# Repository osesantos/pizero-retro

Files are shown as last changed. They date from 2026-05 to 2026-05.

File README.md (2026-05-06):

## Table of Contents

- [Differences from Anemoia-ESP32](#differences-from-anemoia-esp32)
- [Hardware Overview](#hardware-overview)
  - [Parts List](#parts-list)
  - [Wiring](#wiring)
    - [ILI9341 Display](#ili9341-display)
    - [Tactile Buttons](#tactile-buttons)
- [Software Setup](#software-setup)
  - [Step 1 - Install RetroPie](#step-1---install-retropie)
  - [Step 2 - Configure the SPI Display](#step-2---configure-the-spi-display)
  - [Step 3 - Configure GPIO Buttons](#step-3---configure-gpio-buttons)
  - [Step 4 - Add ROMs](#step-4---add-roms)
- [3D Model & Enclosure](#3d-model--enclosure)
- [Contributing](#contributing)
- [License](#license)

---

## Differences from Anemoia-ESP32

| Aspect | Anemoia-ESP32 | Anemoia-PiZero |
|---|---|---|
| Board | ESP32 (dual-core) | Raspberry Pi Zero (no W) |
| OS / Runtime | Arduino / bare metal | RetroPie (Raspberry Pi OS + RetroArch)|
| Display | ST7789 or ILI9341 SPI TFT | ILI9341 SPI TFT (240×320) |
| Audio | PAM8403 amplifier + speaker | None (not implemented yet) |
| ROM storage | Separate SPI microSD module | ROMs on the main OS SD card |
| Input | Various controllers | 8 tactile push buttons (GPIO) |
| Power | Battery + TP4056 charger | USB power only (no battery) |
| PCB | Custom PCB options | Hand-wired (wires / proto board) |

---

## Hardware Overview

### Parts List

| Part | Specification | Notes |
|---|---|---|
| Raspberry Pi Zero | Any revision | Pi Zero 2 W gives better emulation performance |
| SPI TFT display | ILI9341, 240×320, 2.8" | Bare module, not a touchscreen variant |
| Tactile push buttons | 12×12mm body | **6mm or 6.5mm stem height** — see note below |
| Proto board | 5×7 cm (50×70mm) | Elegoo or equivalent, 2.54mm pitch |
| MicroSD card | 8GB minimum, Class 10 | For OS + ROMs |
| USB power supply | 5V / 1A via Micro-USB | Standard phone charger works |
| Hookup wire | 28 AWG stranded | ~30cm total; solid core also works inside case |
| M2.5 × 6mm screws | Self-tapping | ×2, to mount proto board to case standoffs |
| Solder, flux | — | Standard 60/40 or lead-free |

> [!WARNING]
> **Button stem height is critical.** The top shell inner cavity is approximately 7mm deep.
> Standard 12×12×7.3mm tactile buttons (the most common size) will be 0.3mm too tall and will
> prevent the case from closing cleanly. Use **12×12×6mm** or **12×12×6.5mm** buttons, or
> carefully sand the stem tips down ~0.5mm before assembly. Test-fit the buttons in the case
> before soldering them to the proto board.

> [!NOTE]
> No audio amplifier or speaker is needed for this build. Audio support may be added in a future revision.

---

### Physical Assembly

#### Overview

The Pi Zero is soldered **directly to the proto board** (no 40-pin header) using short wire
bridges. This keeps the total stack height to ~7.5mm, which fits inside the 13mm bottom cavity
with clearance.

```
Bottom shell cavity (13mm deep)
  └── Proto board (1.6mm)
      └── Wire bridges (2mm)
          └── Pi Zero PCB (1.4mm)
              └── USB Micro-B connectors (2.5mm, bottom edge only)
                                                Total stack: ~7.5mm
```

#### Step 1 — Prepare the proto board

1. Cut the 5×7cm proto board to **65×50mm** if you want a tighter fit, or leave full-size
   (70×50mm) — both fit inside the case footprint (available X = 85→150mm = 65mm, Y = full width).
2. Mark the positions of the two Pi Zero mounting holes on the proto board. The Pi Zero's
   mounting holes are 3.5mm diameter, spaced **58mm × 23mm** centre-to-centre
   (at 3.5mm from each corner of the 65×30mm PCB edge).

#### Step 2 — Mount the Pi Zero to the proto board

1. Lay the Pi Zero face-up on the proto board, aligning the mounting holes.
2. Solder short (~10mm) wire bridges from each of the Pi Zero's 40 GPIO pads to the nearest
   proto board through-holes. You only need to bridge the pins you are actually using
   (see wiring table below) — you do not need to bridge all 40 pins.
3. **Minimum required bridges:**
   - Pin 1 (3.3V) — for display VCC
   - Pin 2 or 4 (5V) — not used in this build, skip
   - All GND pins used (Pin 6, Pin 20, Pin 14 — connect together on proto board)
   - All signal pins from the wiring tables (SPI + GPIO buttons)
4. Use a thin bead of **epoxy or hot glue** along the Pi Zero short edges to mechanically
   bond it to the proto board once you are satisfied with the wiring.

#### Step 3 — Wire the display

Run 28 AWG wires from the ILI9341 module directly to the proto board pads corresponding to
each GPIO pin. Keep wires short — route them flat against the proto board before entering the
case. The display module sits inside the top shell, held in place by the screen window bezel.

> [!TIP]
> Solder the display wires **last**, after the Pi Zero is bonded and all button wires are run.
> The display wires cross the case interior and need to be the correct length to reach the module
> without pulling tight or bunching up.

#### Step 4 — Wire the buttons

Each button has four legs in a 12×12mm square pattern; legs on opposite sides are internally
connected. Solder one leg to a GND rail on the proto board and the diagonal leg to the
corresponding GPIO wire. Buttons sit in the top shell button holes — route wires down through
the parting line gap and to the proto board.

> [!TIP]
> Use a 10cm length of wire per button before trimming. After a test fit inside the case,
> trim to the correct length and re-solder.

#### Step 5 — Seat in the case

1. Place the assembled proto board (Pi Zero face-up) into the **bottom shell**, positioning it
   so the Pi Zero USB PWR and OTG port openings align with the two Micro-USB cutouts on the
   bottom edge of the case.
   - Pi Zero left edge should align with approximately **X = 85mm** from the left end of the case.
2. Secure with **2× M2.5 × 6mm self-tapping screws** through the case floor standoffs into the
   Pi Zero mounting holes. Alternatively, use **3M VHB double-sided tape** under the proto board.
3. Route the ILI9341 module wires up to the top shell, then press-fit the display module into
   the screen window bezel.
4. Snap the top and bottom shells together. The shells are held by friction clips; no screws needed.

---

### Wiring

Anemoia-PiZero Wiring Diagram

All connections are hand-wired. The Pi Zero uses 3.3V logic on all GPIO pins, which is directly compatible with the ILI9341 display.

#### ILI9341 Display

The display is connected to the Pi Zero's hardware SPI0 bus.

| ILI9341 Signal | Pi Zero Pin | GPIO  |
|---|---|---|
| VCC | Pin 17 | 3.3V  |
| GND | Pin 20 | GND |
| CS | Pin 24 | GPIO8 (CE0) |
| RESET | Pin 22 | GPIO25 |
| DC / RS | Pin 18 | GPIO24 |
| MOSI / SDI | Pin 19 | GPIO10 (MOSI) |
| SCK / CLK | Pin 23 | GPIO11 (SCLK) |
| LED / BL | Pin 17 | 3.3V (always on) |
| MISO | - | Not connected |

> [!NOTE]
> The backlight (LED/BL) pin can be connected directly to 3.3V for always-on operation, or to a GPIO pin if you want software brightness control later.

---

#### Tactile Buttons

Each button connects between a GPIO pin and GND. The Pi's internal pull-up resistors are enabled in software.

| NES Button | Pi Zero Pin | GPIO |
|---|---|---|
| A | Pin 29 | GPIO5  |
| B | Pin 31 | GPIO6  |
| Up | Pin 33 | GPIO13 |
| Down | Pin 35 | GPIO19 |
| Left | Pin 36 | GPIO16 |
| Right | Pin 38 | GPIO20 |
| Start | Pin 40 | GPIO21 |
| Select | Pin 37 | GPIO26 |

> [!NOTE]
> These GPIO assignments are suggestions. You can remap them during the RetroArch controller configuration step. Avoid GPIO2, GPIO3 (I2C), and GPIO14/15 (UART) to prevent conflicts.

---

## Software Setup

### Step 1 - Install RetroPie

1. Download the latest **RetroPie** image for **Raspberry Pi Zero / Zero W** from the [official RetroPie website](https://retropie.org.uk/download/).
2. Flash the image to your microSD card using [Raspberry Pi Imager](https://www.raspberrypi.com/software/) or [balenaEtcher](https://etcher.balena.io/).
3. Insert the SD card into your Pi Zero and boot it up connected to an HDMI monitor first to complete initial setup.

---

### Step 2 - Configure the SPI Display

The ILI9341 display is driven by [`fbcp-ili9341`](https://github.com/juj/fbcp-ili9341) — a userspace SPI display driver that reads `/dev/fb0` (the HDMI virtual framebuffer) and pushes it directly to the ILI9341 over `/dev/spidev0.0`. This requires no kernel module or device tree overlay, and works on all Pi kernel versions.

> [!NOTE]
> The `dtoverlay=fbtft,...` and `fbtft_device` module approaches both fail on the kernel version (`5.10.x`) shipped with current RetroPie for Pi Zero. Use `fbcp-ili9341` instead.

#### 2a — Enable SPI and set the HDMI virtual resolution

Mount the SD card on your PC, or SSH/edit directly on the Pi, and open `/boot/config.txt`. Append the contents of `config/boot_config.txt` from this repo (or copy the lines below):

```
# Enable SPI bus (required for the ILI9341 display)
dtparam=spi=on

# Force HDMI output at 320x240.
# fbcp-ili9341 reads /dev/fb0 and pushes it directly to the ILI9341 over SPI.
# These settings are required even if no HDMI monitor is connected.
hdmi_force_hotplug=1
hdmi_group=2
hdmi_mode=87
hdmi_cvt=320 240 60 1 0 0 0
```

#### 2b — Install fbcp-ili9341

SSH into the Pi and run:

```bash
sudo apt update
sudo apt install -y cmake
git clone https://github.com/juj/fbcp-ili9341.git
cd fbcp-ili9341
mkdir build && cd build
cmake -DILI9341=ON \
      -DSPI_BUS_CLOCK_DIVISOR=6 \
      -DGPIO_TFT_DATA_CONTROL=24 \
      -DGPIO_TFT_RESET_PIN=25 \
      -DDISPLAY_ROTATE_180_DEGREES=ON \
      -DBACKLIGHT_CONTROL=OFF \
      -DSTATISTICS=0 \
      ..
make -j$(nproc)
sudo install fbcp-ili9341 /usr/local/bin/fbcp-ili9341
```

Parameter notes:
- `-DILI9341=ON` — selects the ILI9341 driver
- `-DSPI_BUS_CLOCK_DIVISOR=6` — sets SPI clock to `core_freq / 6` ≈ 66 MHz (safe default; increase divisor if you see corruption)
- `-DGPIO_TFT_DATA_CONTROL=24` — DC pin = GPIO24 (Pin 18)
- `-DGPIO_TFT_RESET_PIN=25` — RESET pin = GPIO25 (Pin 22)
- `-DDISPLAY_ROTATE_180_DEGREES=ON` — landscape orientation; swap for `OFF` if the image is upside-down
- `-DBACKLIGHT_CONTROL=OFF` — backlight is wired directly to 3.3V, not a GPIO
- `-DSTATISTICS=0` — disables on-screen FPS overlay

#### 2c — Test before enabling autostart

Run it manually first to confirm the display works:

```bash
sudo fbcp-ili9341
```

The RetroPie interface should appear on the screen. Press `Ctrl+C` to stop.

#### 2d — Enable autostart at boot

Add to `/etc/rc.local` before `exit 0`:

```bash
/usr/local/bin/fbcp-ili9341 &
```

If a previous `fbcp &` line exists in `/etc/rc.local`, replace it rather than adding a second line:

```bash
sudo sed -i 's|fbcp &|/usr/local/bin/fbcp-ili9341 \&|' /etc/rc.local
```

Reboot. The RetroPie interface should appear on the SPI display on every boot.

> [!TIP]
> If colours look wrong (red/blue swapped), add `-DCOLOR_ORDER_BGR=ON` to the `cmake` command and recompile. If the image is mirrored, swap `-DDISPLAY_ROTATE_180_DEGREES` between `ON` and `OFF`.

---

### Step 3 - Configure GPIO Buttons

GPIO buttons are handled by [Adafruit's `retrogame`](https://github.com/adafruit/Adafruit-Retrogame) — a userspace daemon that reads GPIO pins and emits keyboard events via `/dev/uinput`, making the buttons visible to EmulationStation and RetroArch.

#### 3a — Install retrogame

SSH into the Pi and run:

```bash
sudo apt-get install -y git
git clone https://github.com/adafruit/Adafruit-Retrogame.git
cd Adafruit-Retrogame
make
sudo cp retrogame /usr/local/bin/retrogame
```

#### 3b — Install the GPIO config file

Copy `config/retrogame.cfg` from this repo to `/boot/retrogame.cfg` on the Pi:

```bash
sudo cp retrogame.cfg /boot/retrogame.cfg
```

The config maps each button to a key code using the GPIO numbers from the [Tactile Buttons](#tactile-buttons) table:

| Button | GPIO | Key emitted |
|---|---|---|
| A | 5 | Left Ctrl |
| B | 6 | Left Alt |
| Up | 13 | Up arrow |
| Down | 19 | Down arrow  |
| Left | 16 | Left arrow  |
| Right  | 20 | Right arrow |
| Start  | 21 | Enter |
| Select | 26 | Escape |

> [!NOTE]
> `/boot/retrogame.cfg` is watched live by the daemon — edits take effect immediately without restarting `retrogame`.

#### 3c — Enable autostart at boot

Add to `/etc/rc.local` before `exit 0`:

```bash
/usr/local/bin/retrogame &
```

Reboot and confirm it is running:

```bash
ps aux | grep retrogame
```

#### 3d — Test button events

Install `evtest` and verify events are emitted when buttons are pressed:

```bash
sudo apt-get install -y evtest
sudo evtest
# Select the retrogame device and press each button
```

#### 3e — Configure RetroArch input mapping

The default RetroArch input config (`/opt/retropie/configs/all/retroarch.cfg`) maps player 1 to WASD-style keys, which do **not** match the key codes emitted by `retrogame`. You must update it to match the key codes from the table above, otherwise only Start will work in-game.

Run the following to update the mappings and add a **Select + Start** hotkey combo to exit games:

```bash
sudo sed -i \
  -e 's/^input_player1_a = .*/input_player1_a = "ctrl"/' \
  -e 's/^input_player1_b = .*/input_player1_b = "alt"/' \
  -e 's/^input_player1_select = .*/input_player1_select = "escape"/' \
  -e 's/^input_player1_left = .*/input_player1_left = "left"/' \
  -e 's/^input_player1_right = .*/input_player1_right = "right"/' \
  -e 's/^input_player1_up = .*/input_player1_up = "up"/' \
  -e 's/^input_player1_down = .*/input_player1_down = "down"/' \
  /opt/retropie/configs/all/retroarch.cfg

echo -e "\ninput_enable_hotkey = \"escape\"\ninput_exit_emulator = \"enter\"" | sudo tee -a /opt/retropie/configs/all/retroarch.cfg
```

This results in the following effective mapping:

| Button | Key emitted by retrogame | RetroArch action |
|---|---|---|
| A | Left Ctrl | A |
| B | Left Alt | B |
| Up | Up arrow | D-pad up |
| Down | Down arrow | D-pad down |
| Left | Left arrow | D-pad left |
| Right  | Right arrow | D-pad right |
| Start  | Enter | Start |
| Select | Escape | Select |
| Select + Start | Escape + Enter | **Exit game** |

> [!NOTE]
> With `input_enable_hotkey = "escape"` set, Select becomes a modifier key for hotkey combos and no longer sends a bare ESC to the game. This is fine for all supported systems since Select is a game button, not an OS key.

#### 3f — Configure EmulationStation input mapping

On first launch (or after deleting the input config), EmulationStation will prompt you to map the controller. Press and hold any button to begin, then follow the on-screen prompts.

To reset the mapping and start over:

```bash
rm /opt/retropie/configs/all/emulationstation/es_input.cfg
```

Then restart EmulationStation — it will re-prompt for input configuration automatically.

---

### Step 4 - Add ROMs

1. Copy your legally obtained `.nes` ROM files to the following directory on the SD card:

```
/home/pi/RetroPie/roms/nes/
```

You can do this by:
- Mounting the SD card on your PC and copying files directly, or
- Using a USB drive: create a folder `retropie/roms/nes/` on the USB drive, plug it into the Pi, wait 30 seconds, then copy ROMs to the populated folder.

2. Restart EmulationStation. Your ROMs will appear in the NES game list.

---

## 3D Model & Enclosure

The original enclosure and 3D models from Anemoia-ESP32 are reused unchanged. All files are available in the `/3d-model` folder.

> [!NOTE]
> The Pi Zero has the same compact form factor as the ESP32 DevKit used in the original design. Minor modifications to the PCB mount points may be required depending on your specific Pi Zero revision. The hand-wired approach means no custom PCB is needed.

---

## Contributing

Pull requests are welcome. For major changes, please open an issue first to discuss what you would like to change.

---

## License

This project is licensed under the GNU General Public License v3.0 (GPLv3) - see the [LICENSE](LICENSE) file for more details.

Original Anemoia-ESP32 project by [Shim06](https://github.com/Shim06/Anemoia-ESP32).

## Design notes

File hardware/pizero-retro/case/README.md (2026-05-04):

# Anemoia-PiZero Case Files

OpenSCAD modifications to the original Anemoia-ESP32 module-based enclosure,
adapted for the Raspberry Pi Zero build.

---

## Files

| File | Description |
|---|---|
| `Anemoia-PiZero-Bottom.scad` | Modified bottom shell — removes ESP32-era port holes, adds Pi Zero USB port slots and standoff pilot holes |
| `Anemoia-PiZero-Top.scad` | Top shell — imported unchanged; screen window and button holes are already correct. Contains optional screen window widening parameters if needed. |

Both files import the original STLs from `3d-model/Anemoia-ESP32/` by relative
path. **Open the `.scad` files from the repo root, or adjust the `original_stl`
path at the top of each file if you open them from a different working directory.**

---

## What changed from the original

### Bottom shell

| Change | Original | Pi Zero |
|---|---|---|
| Left wall cutout | Micro-USB charging port (TP4056) | **Filled/removed** |
| Right wall cutout | SS12F17 power switch slot | **Filled/removed** |
| Bottom edge | No cutouts | **2× Micro-USB slots added** (PWR + OTG) |
| Floor standoffs | ESP32-DevKit mounting pattern | **2× M2.5 pilot holes added** for Pi Zero |

### Top shell

No structural changes. The existing 70mm screen window fits a standard
ILI9341 2.8" module in landscape orientation. Button holes are unchanged.

---

## Pi Zero placement inside the case

```
Case X axis (174mm wide, landscape):
  0mm ─────[buttons]──── 52mm ────[screen]──── 122mm ────[Pi Zero]──── 174mm
                                                            85mm        150mm

Pi Zero PCB: X = 85 → 150mm
  USB PWR port centre: X ≈ 105.5mm  (slot on bottom edge)
  USB OTG port centre: X ≈ 122.5mm  (slot on bottom edge)
  MicroSD card: underside at X ≈ 145mm — accessed by opening the case, no wall slot needed
```

---

## How to render and export

1. Open `Anemoia-PiZero-Bottom.scad` in OpenSCAD.
2. Press **F6** to render (may take 1–2 minutes — the STL import is large).
3. Go to **File → Export → Export as STL** and save as `Anemoia-PiZero-Bottom.stl`.
4. Repeat for `Anemoia-PiZero-Top.scad` → `Anemoia-PiZero-Top.stl`.
5. Slice both STLs with your slicer of choice.

> [!NOTE]
> OpenSCAD's preview mode (F5) renders the STL import as a grey placeholder —
> this is normal. Use F6 (full render) to see the actual geometry with all
> modifications applied.

---

## Recommended print settings

| Setting | Value |
|---|---|
| Material | PLA or PETG |
| Layer height | 0.2mm |
| Infill | 20% gyroid |
| Walls | 3 perimeters |
| Supports | None required (both shells print flat-side down) |
| Bed adhesion | Brim (recommended for the top shell — long thin part) |

---

## Standoff notes

The bottom shell has four existing standoffs from the original design.
The `.scad` file drills **M2.5 pilot holes** (2.7mm diameter) into the standoffs
nearest to the Pi Zero mounting hole positions.

Use **M2.5 × 6mm self-tapping screws** to secure the proto board assembly.
If the standoffs are not in a convenient position after a test fit, use
**double-sided foam tape** (3M VHB) instead — this is adequate for a USB-only
powered build with no vibration.

---

## Adjusting the screen window

If your specific ILI9341 module has a wider PCB than expected, open
`Anemoia-PiZero-Top.scad` and set:

```scad
screen_trim_enable = true;
screen_trim_left   = 2;   // mm to add on left
screen_trim_right  = 2;   // mm to add on right
```

Then re-render and export.

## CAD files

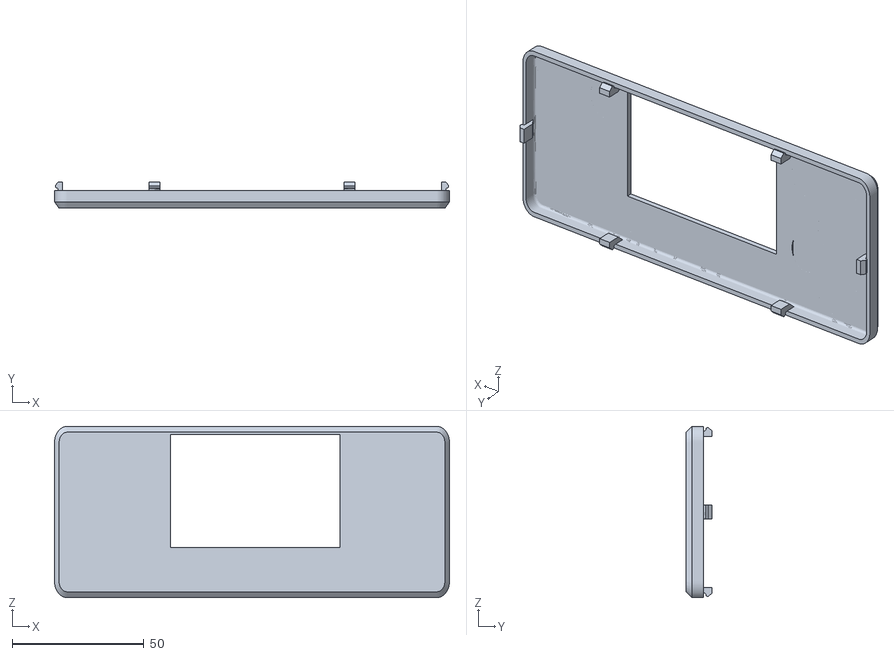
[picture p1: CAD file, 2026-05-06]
3d-model/pizero/top.stl
150.0 x 10.0 x 65.0

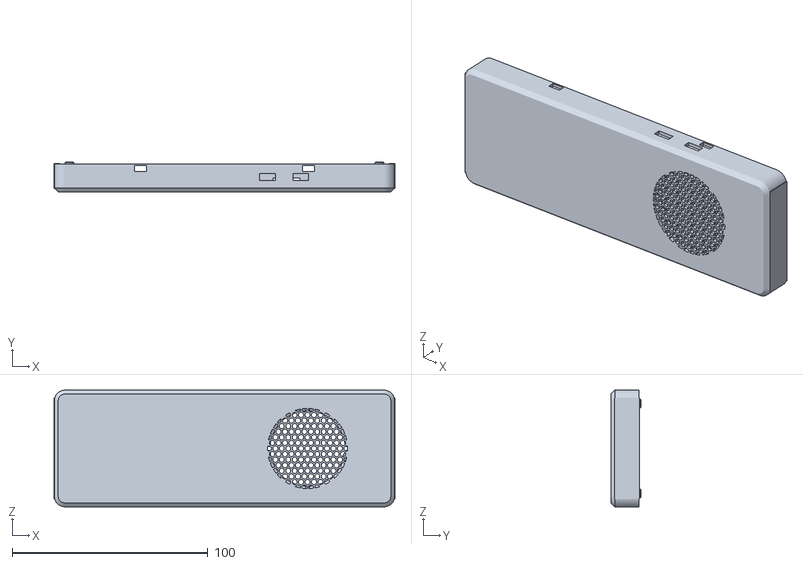
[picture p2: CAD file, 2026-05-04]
hardware/Anemoia-PiZero/case/Anemoia-PiZero-Bottom.stl
174.4 x 15.4 x 59.7

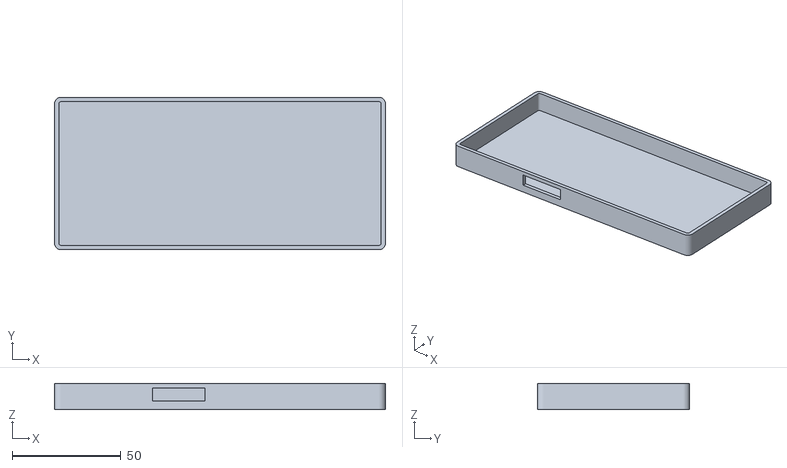
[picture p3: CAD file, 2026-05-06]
hardware/pizero-retro/case/pizero-retro-Bottom.stl
152.0 x 70.0 x 12.0

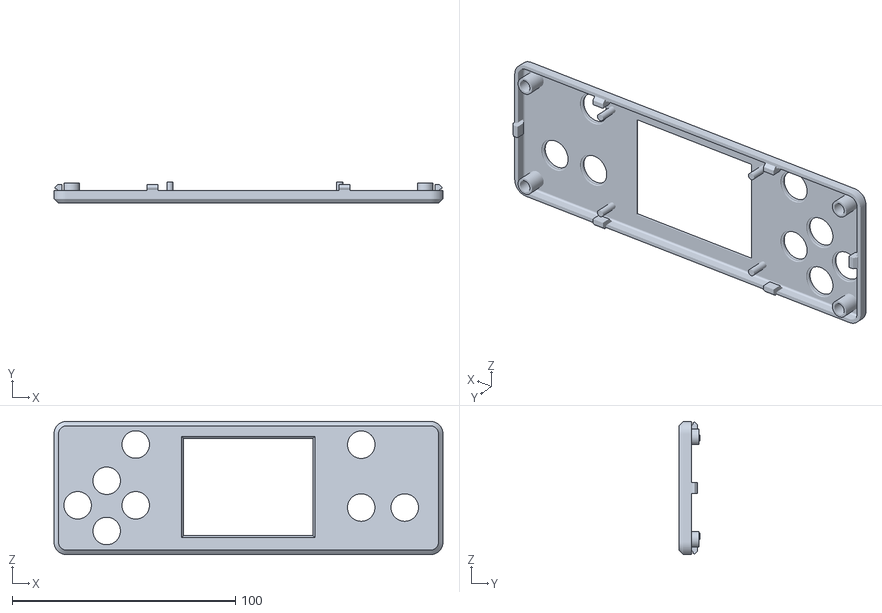
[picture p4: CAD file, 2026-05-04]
hardware/Anemoia-PiZero/case/Anemoia-PiZero-Top.stl
174.2 x 9.60 x 59.7

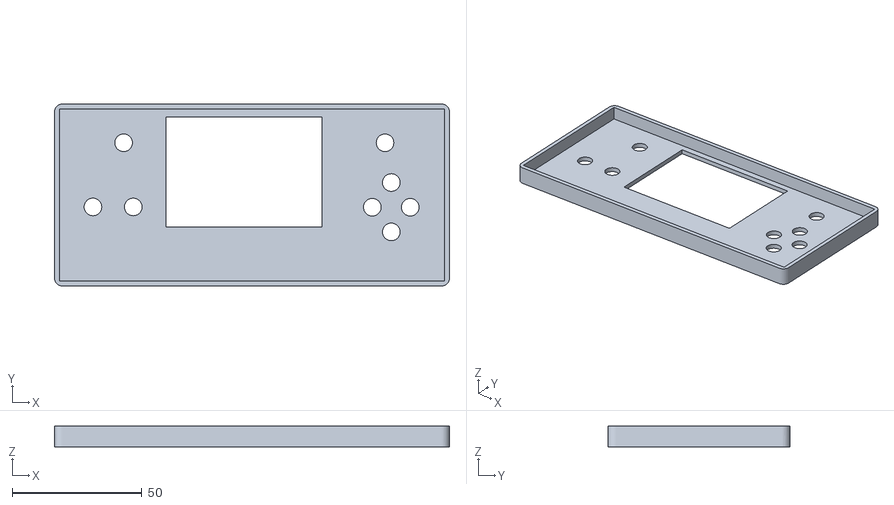
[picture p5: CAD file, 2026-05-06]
hardware/pizero-retro/case/pizero-retro-Top-1.stl
152.0 x 70.0 x 8.00

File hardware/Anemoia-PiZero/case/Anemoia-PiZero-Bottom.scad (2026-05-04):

// =============================================================================
// Anemoia-PiZero — Bottom Shell
// =============================================================================
// Modifies the original Anemoia-ESP32 bottom shell for use with a
// Raspberry Pi Zero build.
//
// Changes from the original ESP32 bottom shell:
//   1. Left side-wall hole (TP4056 Micro-USB charger) is plugged.
//   2. Right side-wall hole (SS12F17 power switch) is plugged.
//   3. Two Micro-USB port slots are cut through the top wall for the
//      Pi Zero's PWR and OTG ports (Pi processor faces up toward top shell).
//   4. Four new M2.5 standoff cylinders are added to the inner floor,
//      positioned for the Pi Zero 58 × 23 mm mounting-hole pattern.
//      Each standoff has a 2.7 mm pilot hole for an M2.5 × 6 mm self-tapping
//      screw.
//
// ── Coordinate system (inherited from original STL) ───────────────────────────
//   X :   -3.6  →  170.6 mm   case width  (174 mm, landscape)
//   Y :    0.4  →   15.8 mm   case depth  (Y=0.4  outer back face,
//                                           Y=15.8 parting seam / open face)
//   Z :  -57.1  →    2.6 mm   case height (Z= 2.6  top wall outer face,
//                                           Z=-57.1 bottom wall outer face)
//
// ── Walls ─────────────────────────────────────────────────────────────────────
//   Inner cavity floor    :  Y ≈ 2.0 mm  (floor of the component well)
//   Top wall inner face   :  Z ≈ 1.0 mm  (→ outer face Z=2.6, ~1.6 mm thick)
//   Side walls (X=-3.6 / X=170.6): short walls, ~2 mm thick
//
// ── Pi Zero placement ─────────────────────────────────────────────────────────
//   Pi Zero PCB            :  X = 85 → 150 mm  (65 × 30 mm PCB)
//   Processor              :  facing UP (toward top shell / parting face)
//   USB PWR port centre    :  X ≈ 105.5 mm, exits through top wall (Z = 2.6)
//   USB OTG port centre    :  X ≈ 122.5 mm, exits through top wall (Z = 2.6)
//   MicroSD card           :  underside at X ≈ 145 mm — no wall slot needed
//
// ── Pi Zero mounting-hole pattern ─────────────────────────────────────────────
//   Hole spacing           :  58 mm (X) × 23 mm (Z)
//   PCB centred in X from 85 mm : margin = (65−58)/2 = 3.5 mm
//   Standoff centres (X)   :  88.5 mm  and  146.5 mm
//   Standoff centres (Z)   :  pizero_z_centre − 11.5 mm  and  + 11.5 mm
//     where pizero_z_centre is the midpoint of the Pi Zero along Z (configurable).
//
// Dependencies:
//   Requires the original ESP32 bottom STL at the relative path below.
//   Render (F6) and export as Anemoia-PiZero-Bottom.stl for slicing.
// =============================================================================

// ── Path to the original bottom shell STL ────────────────────────────────────
original_stl = "../../../3d-model/Anemoia-ESP32/Anemoia-ESP32-Bottom.stl";

// ── Tolerances ────────────────────────────────────────────────────────────────
tol = 0.3;   // general fit tolerance (added to slot/hole dims)
eps = 0.1;   // small overlap to avoid coincident-face artefacts

// =============================================================================
// USB port slot parameters
// =============================================================================
// Micro-USB connector body: ~7.5 mm wide × ~2.8 mm tall.
// Added tol on each dimension for clearance.

usb_slot_w = 7.5 + tol * 2;   // slot width  in X  (≈ 8.1 mm)
usb_slot_h = 2.8 + tol * 2;   // slot height in Y  (≈ 3.4 mm)

// Port centres on the Pi Zero (X axis)
usb_pwr_x = 105.5;
usb_otg_x = 122.5;

// Top wall: outer Z=2.6, inner Z=1.0  →  cut from Z=1.0−eps through Z=2.6+eps
top_wall_z_inner = 1.0;
top_wall_z_outer = 2.6;

// Slot Y span: centred in the wall depth (Y=0.4 … 15.8).
// The Pi Zero PCB sits near the parting face, so we centre the slot
// in the full wall depth to give cable clearance on both sides.
wall_y_min = 0.4;
wall_y_max = 15.8;
slot_y_centre = (wall_y_min + wall_y_max) / 2;   // ≈ 8.1 mm

// =============================================================================
// Pi Zero standoff parameters
// =============================================================================
// New raised standoff cylinders added to the inner floor (Y=2.0).

standoff_od    = 5.0;    // outer diameter of standoff post (mm)
standoff_h     = 3.5;    // height above the inner floor (mm)
pilot_hole_d   = 2.7;    // M2.5 pilot hole diameter (mm)

// Pi Zero PCB starts at X=85 mm; 65 mm PCB, mounting holes 58 mm apart in X.
//   Margin from PCB edge to hole centre = (65 - 58) / 2 = 3.5 mm
pizero_x_left  = 85.0 + 3.5;   //  88.5 mm
pizero_x_right = 85.0 + 3.5 + 58.0;   // 146.5 mm

// Z centre for the Pi Zero: place it roughly mid-height of the case interior.
// Inner Z range (inside cavity) ≈ -55 to 1.  Pi Zero PCB is 30 mm tall.
// Position the Pi Zero Z centre at Z = -20 (adjust after test fit).
pizero_z_centre = -20.0;
pizero_z_top    = pizero_z_centre + 11.5;   //  -8.5 mm
pizero_z_bot    = pizero_z_centre - 11.5;   // -31.5 mm

// Inner floor Y position (standoffs sit on the floor)
floor_y = 2.0;

// =============================================================================
// Plug dimensions for the original ESP32 side-wall holes
// =============================================================================
// Original holes (measured from STL edge triangles):
//   Both left and right holes span Z = -53 → -1.5, Y = 2.4 → 14.8
//   Left  hole : X outer face at X = -3.6, inner face at X ≈ -1.0
//   Right hole : X outer face at X = 170.6, inner face at X ≈ 168.6

plug_z0 = -53.0 - eps;
plug_z1 = -1.5  + eps;
plug_y0 =   2.4 - eps;
plug_y1 =  14.8 + eps;
plug_thickness = 3.0;   // enough to completely fill & slightly overfill

// =============================================================================
// Helper modules
// =============================================================================

// A single micro-USB slot through the top wall, centred at x_centre.
module usb_slot(x_centre) {
    translate([x_centre - usb_slot_w / 2,
               slot_y_centre - usb_slot_h / 2,
               top_wall_z_inner - eps])
        cube([usb_slot_w,
              usb_slot_h,
              (top_wall_z_outer - top_wall_z_inner) + eps * 2]);
}

// A single Pi Zero standoff post with M2.5 pilot hole.
// Placed at (x, floor_y, z); post extends in the +Y direction (into the open cavity).
// OpenSCAD cylinders are Z-axis aligned; rotate −90° around X to point in +Y.
module pizero_standoff(x, z) {
    translate([x, floor_y, z])
    rotate([-90, 0, 0])          // Z→+Y : cylinder now grows in +Y from Y=floor_y
    difference() {
        cylinder(h = standoff_h, d = standoff_od,   center = false, $fn = 32);
        cylinder(h = standoff_h + eps, d = pilot_hole_d, center = false, $fn = 32);
    }
}

// =============================================================================
// Main model
// =============================================================================

union() {
    difference() {
        // ── 1. Original ESP32 bottom shell ────────────────────────────────────
        import(original_stl, convexity = 10);

        // ── 3. Micro-USB slots through the top wall ───────────────────────────
        usb_slot(usb_pwr_x);
        usb_slot(usb_otg_x);
    }

    // ── 2. Plug the original ESP32 side-wall holes ────────────────────────────

    // Left wall plug (fills TP4056 charging-port hole)
    translate([-3.6 - eps, plug_y0, plug_z0])
        cube([plug_thickness + eps, plug_y1 - plug_y0, plug_z1 - plug_z0]);

    // Right wall plug (fills power-switch hole)
    translate([170.6 - plug_thickness, plug_y0, plug_z0])
        cube([plug_thickness + eps, plug_y1 - plug_y0, plug_z1 - plug_z0]);

    // ── 4. Pi Zero standoff posts ─────────────────────────────────────────────
    pizero_standoff(pizero_x_left,  pizero_z_top);
    pizero_standoff(pizero_x_right, pizero_z_top);
    pizero_standoff(pizero_x_left,  pizero_z_bot);
    pizero_standoff(pizero_x_right, pizero_z_bot);
}

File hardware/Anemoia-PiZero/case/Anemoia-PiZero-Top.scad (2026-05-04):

// =============================================================================
// Anemoia-PiZero — Top Shell
// =============================================================================
// Modifies the original Anemoia-ESP32 module-based top shell for use with
// a Raspberry Pi Zero build.
//
// The top shell requires minimal changes — the screen window and button holes
// are the same dimensions as the original. The only structural difference is
// that the original top shell had no port cutouts (all ports were on the bottom
// shell's side walls), so nothing needs to be plugged.
//
// This file exists as a clean base for any future modifications (e.g. slightly
// widening the screen window if your specific ILI9341 module PCB is wider,
// or adding a label recess). For now it imports the original STL unchanged.
//
// Coordinate system (inherited from original STL):
//   X :   -3.6 → 170.6 mm   case width  (landscape)
//   Y :   -0.2 → 9.4 mm     case depth  (top half thickness, ~9.6mm)
//   Z : -122.8 → -63.1 mm   case height (Z=0 is the top parting seam,
//                                         so top shell Z values are negative)
//
// Screen window (rectangular cutout in the face of the top shell):
//   X : 52 → 122 mm   (70mm wide)
//   Z spans roughly the full height of the shell
//   The ILI9341 module active area (43×57mm landscape) fits comfortably.
//
// Button holes (6× circular through-holes, ~5–6mm diameter):
//   Left  cluster (D-pad):   X ≈ 10–38mm
//   Right cluster (A/B):     X ≈ 132–160mm
//   These are unchanged from the original.
//
// To modify the screen window width (if needed):
//   Uncomment and adjust the SCREEN WINDOW TRIM section below.
//
// Dependencies:
//   Requires the original STL at the relative path below.
//   Render and export as Anemoia-PiZero-Top.stl for slicing.
// =============================================================================

// ── Path to the original top shell STL ───────────────────────────────────────
original_stl = "../../../3d-model/Anemoia-ESP32/Anemoia-ESP32-Top.stl";

// ── Tolerances ────────────────────────────────────────────────────────────────
tol = 0.3;
eps = 0.1;

// =============================================================================
// Optional: Screen window adjustment
// If your ILI9341 module PCB is slightly wider than the existing 70mm window,
// uncomment the difference block below and adjust the trim values.
// =============================================================================

// Screen window current bounds (from STL analysis):
//   X: 52mm → 122mm   (70mm wide)
//   Z: full shell height
// The window is already cut in the original STL — these parameters would WIDEN it.

screen_trim_enable = false;   // set to true to widen the screen window
screen_trim_left   = 0;       // additional mm to remove from left edge of window
screen_trim_right  = 0;       // additional mm to remove from right edge of window
screen_window_x0   = 52;      // current left edge of screen window in X
screen_window_x1   = 122;     // current right edge of screen window in X
screen_window_z0   = -123;    // bottom of shell in Z
screen_window_z1   = -63;     // top of shell in Z
screen_window_y_depth = 12;   // full depth of top shell (cut through)

// =============================================================================
// Main model
// =============================================================================

if (screen_trim_enable) {
    difference() {
        import(original_stl, convexity = 10);

        // Widen screen window on left side
        if (screen_trim_left > 0)
            translate([screen_window_x0 - screen_trim_left - eps,
                       -eps,
                       screen_window_z0 - eps])
                cube([screen_trim_left + eps,
                      screen_window_y_depth + eps * 2,
                      screen_window_z1 - screen_window_z0 + eps * 2]);

        // Widen screen window on right side
        if (screen_trim_right > 0)
            translate([screen_window_x1 - eps,
                       -eps,
                       screen_window_z0 - eps])
                cube([screen_trim_right + eps,
                      screen_window_y_depth + eps * 2,
                      screen_window_z1 - screen_window_z0 + eps * 2]);
    }
} else {
    // No modifications — import original shell as-is
    import(original_stl, convexity = 10);
}

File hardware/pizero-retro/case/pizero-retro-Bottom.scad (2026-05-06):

// =============================================================================
// pizero-retro — Bottom Shell
// =============================================================================
// Pure parametric OpenSCAD — no STL dependency.
//
// Printing orientation : back face DOWN  (Z = 0 is the outer back face).
//                        Parting face at Z = bottom_depth, open toward top shell.
//
// Coordinate system (X, Y across the case outer footprint):
//   X :   0 → 152 mm   (case width,  left → right)
//   Y :   0 →  70 mm   (case height, bottom edge → top edge)
//   Z :   0 →  12 mm   (shell depth, outer back face → parting face)
//
// The back face grows 3 mm beyond the PCB edge on all four sides (expand = 3),
// matching the Top shell. Side walls remain 2 mm thick around the full
// expanded footprint; the 3 mm overhang exists only on the back face.
//
// USB port cutout (24 mm wide × 6 mm tall) in the bottom edge wall (Y = 0):
//   X :  45 →  69 mm   (shifted 4 mm left of original PCB-relative position)
//   Z :   4 →  10 mm   (adjust usb_z_start / usb_z_height if needed)
//
// No screw holes — drill to suit after printing.
// =============================================================================

// ── Smoothness ────────────────────────────────────────────────────────────────
$fn = 64;

// ── Tolerance ─────────────────────────────────────────────────────────────────
eps = 0.1;   // small overlap to avoid coincident-face artefacts

// ── PCB dimensions ────────────────────────────────────────────────────────────
pcb_w = 142;   // mm wide
pcb_h = 60;    // mm tall

// ── Case geometry ─────────────────────────────────────────────────────────────
wall         = 2;                          // back face & side wall thickness (mm)
expand       = 3;                          // extra back-face material beyond PCB on each side
corner_r     = 3;                          // outer corner radius (mm)
inner_r      = max(0, corner_r - wall);    // inner corner radius → 1 mm

case_w       = pcb_w + 2 * wall + 2 * expand;   // 152 mm
case_h       = pcb_h + 2 * wall + 2 * expand;   // 70 mm
bottom_depth = 12;                              // total bottom shell depth (mm)

// ── USB port cutout parameters ────────────────────────────────────────────────
// Rectangular slot through the bottom edge wall (Y = 0 → Y = wall).
// Adjust usb_z_start and usb_z_height to align with your Pi Zero USB ports.
//
// PCB-relative X (expand offset applied in main model). Originally 46 mm in the
// old un-expanded outer coordinate system; shifted 4 mm left → 42 mm PCB-rel
// → outer X = 45 mm after the [expand, …] translate.

usb_x_start  = 42;   // mm from PCB left (outer X = 45 after expand)
usb_w        = 24;   // mm wide  (spans both Pi Zero USB ports)
usb_z_start  = 4;    // mm above the outer back face floor
usb_z_height = 6;    // mm tall  (6 mm suits standard micro-USB connectors)

// ── Helpers ───────────────────────────────────────────────────────────────────

// Solid rounded-rectangle prism
module rounded_box(w, h, d, r) {
    linear_extrude(d)
        hull() {
            translate([r, r])         circle(r = r);
            translate([w - r, r])     circle(r = r);
            translate([r, h - r])     circle(r = r);
            translate([w - r, h - r]) circle(r = r);
        }
}

// ── Main model ────────────────────────────────────────────────────────────────

difference() {

    // 1. Outer shell — expanded footprint (matches Top)
    rounded_box(case_w, case_h, bottom_depth, corner_r);

    // 2. Inner cavity — side walls are exactly `wall` (2 mm) thick around the
    //    full expanded footprint. The back face (Z = 0 → wall) covers the full
    //    152 × 70 mm, so the 3 mm `expand` overhang exists only on the back face.
    translate([wall, wall, wall])
        rounded_box(case_w - 2 * wall,
                    case_h - 2 * wall,
                    bottom_depth - wall + eps,
                    inner_r);

    // 3. USB port cutout — slot through the bottom edge wall (Y = 0).
    //    Wrapped in [expand, expand, 0] so X is PCB-relative; Y still cuts
    //    through the outer wall starting at Y = 0.
    translate([expand + usb_x_start, -eps, usb_z_start])
        cube([usb_w, wall + 2 * eps, usb_z_height]);
}

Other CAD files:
hardware/pizero-retro/case/pizero-retro-Top.stl
hardware/pizero-retro/case/pizero-retro-Top.scad

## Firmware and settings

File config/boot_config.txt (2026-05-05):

# =============================================================================
# Anemoia-PiZero - /boot/config.txt additions
# =============================================================================
# Copy the relevant sections below into the END of your /boot/config.txt on
# the RetroPie SD card, then reboot.
#
# Your full /boot/config.txt is at the root of the FAT32 boot partition and
# can be edited from any PC before first boot.
# =============================================================================

# -----------------------------------------------------------------------------
# Enable SPI bus (required for the ILI9341 display)
# -----------------------------------------------------------------------------
dtparam=spi=on

# -----------------------------------------------------------------------------
# Force HDMI output at 320x240.
# fbcp-ili9341 reads /dev/fb0 and pushes it directly to the ILI9341 over SPI.
# These settings are required even if no HDMI monitor is connected.
# -----------------------------------------------------------------------------
hdmi_force_hotplug=1
hdmi_group=2
hdmi_mode=87
hdmi_cvt=320 240 60 1 0 0 0

# -----------------------------------------------------------------------------
# Optional: disable overscan if you see black borders on an HDMI monitor
# -----------------------------------------------------------------------------
# disable_overscan=1

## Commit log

2026-03-24 fix(config): update I2S pin configuration for ESP32-S3
2026-03-26 feat: add 3d model for PCBs
2026-03-28 fix: update macro for TFT DMA initialization and rendering
2026-04-01 fix: revise default pin configuration
2026-04-25 refactor(pcb): add component designators, reroute power traces, add vias, and adjust trace widths
    [Anemoia-ESP32-SMD_Bottom_Tenting.gbr, Anemoia-ESP32-SMD_Copper_Signal_Bot.gbr, Anemoia-ESP32-SMD_Copper_Signal_Top.gbr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]
2026-04-27 feat: controller over UART (#46)
    * Add ControllerTypes enum for easier to read code and GP_NC for when no controller is connected.
    * Add ControllerTypes enum header
    * Unhide controller options for CYD
    * Add no_controller option for cyd
    * Fix build.yaml controller choices bug
    * Fix enum so it stores uint8_t
    * Add support for receiving button presses over serial.
    * Add Serial1 pin defines for default board
    * Add Serial1 pin defines for other configs
    * Fix URL typo
2026-04-30 ci: add clang-format and cppcheck to CI
    ci: switch to clang-18
    ci: update clang commands
    ci: filter compile_commands.json
    ci: add .clang-tidy config
    ci: update compile_commands.json filter
    ci: update compile_commands.json filter
    ci: update compile_commands.json filter
    ci: upload compile_commands.json
    ci: update
    ci: update .clang-tidy and build.yaml
    ci: replace clang-tidy with cppcheck
    ci: update compile
    ci: update compile command
    Revert "ci: update compile"
    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
2026-05-04 add 3d case
    [Anemoia-PiZero-Bottom.scad, Anemoia-PiZero-Top.scad]
2026-05-05 change screen config
    [boot_config.txt]
2026-05-06 Adding new scad files
    [pizero-retro-Bottom.scad, pizero-retro-Top.scad]
2026-05-06 update stls
    [pizero-retro-Bottom.stl, pizero-retro-Top.stl]
2026-05-06 update top
    [pizero-retro-Top.scad, pizero-retro-Top.stl]
2026-05-06 update bottom
    [pizero-retro-Bottom.scad, pizero-retro-Bottom.stl]
